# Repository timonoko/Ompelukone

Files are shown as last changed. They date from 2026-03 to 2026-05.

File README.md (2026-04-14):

Merkittävää kenties se, että käytin zero-detecting optotriaccia, vaikka tekoäly suositteli analogista ratkaisua.
Uusi 11 millisekunnin kytkentätaajuus tuottaa satunnaisesti 10 ms half-cycle pulsseja ja meno on tasasta kuin modellinukella kaubamajan akkunassa.

Ei mikä tahansa rampparulla. Singer Slant-o-matic 1957 maksaa satasia Ebayssa.

Jos käynnistää kaasu pohjassa, se kytkeytyy nettiin ja siitä tulee webrepl-serveri.

Ompelukokemus on paljastanut, että vehje on niin hyvissä rasvoissa, että käyntiinlähtötilanne on hieman epämääräinen ja tahmea. Siksi siinä on nyt 40ms pulssi, joka nykäiseen moottorin liikkeelle.

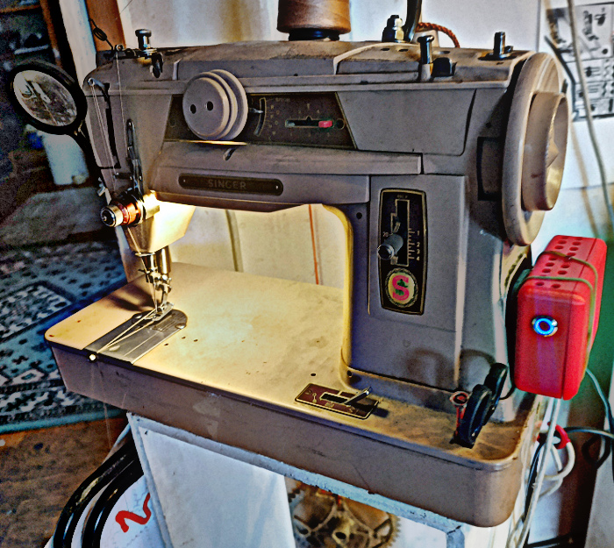
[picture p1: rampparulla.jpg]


Nyt siinä vauhtianturi, joka on Walkman kasettimankan moottori.

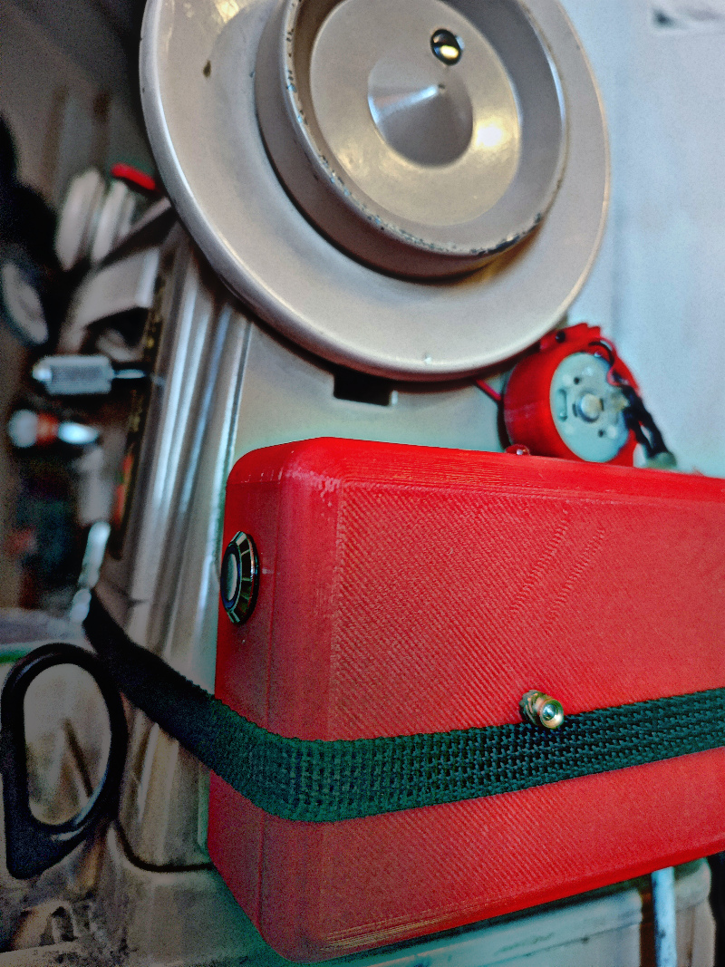
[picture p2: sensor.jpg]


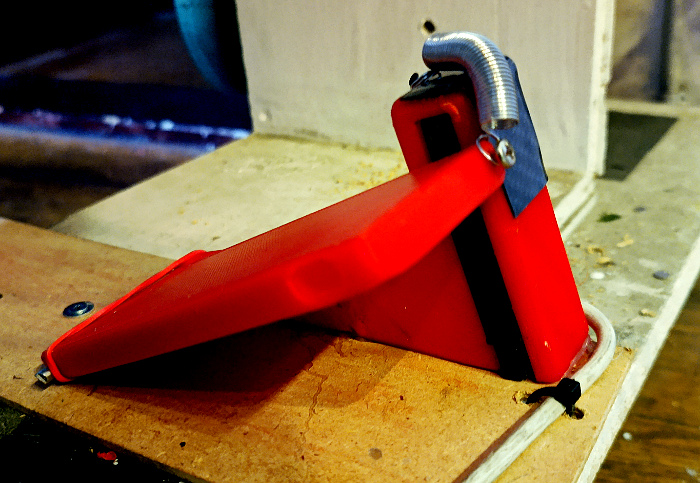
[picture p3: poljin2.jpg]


https://youtube.com/shorts/d1vxEruO6-g?si=aJA7WQgHlC6sGKzD

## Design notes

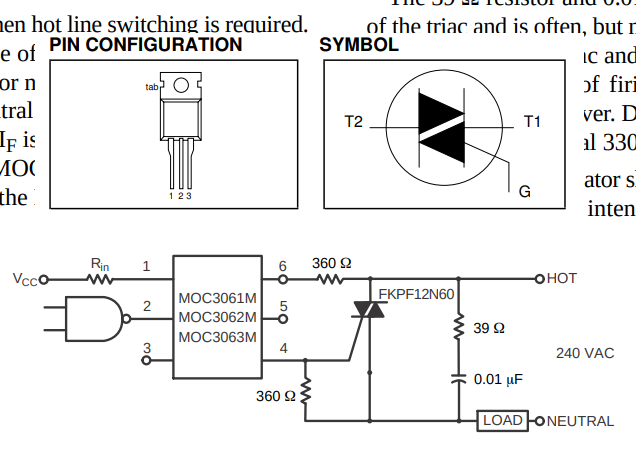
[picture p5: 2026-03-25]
triac.png

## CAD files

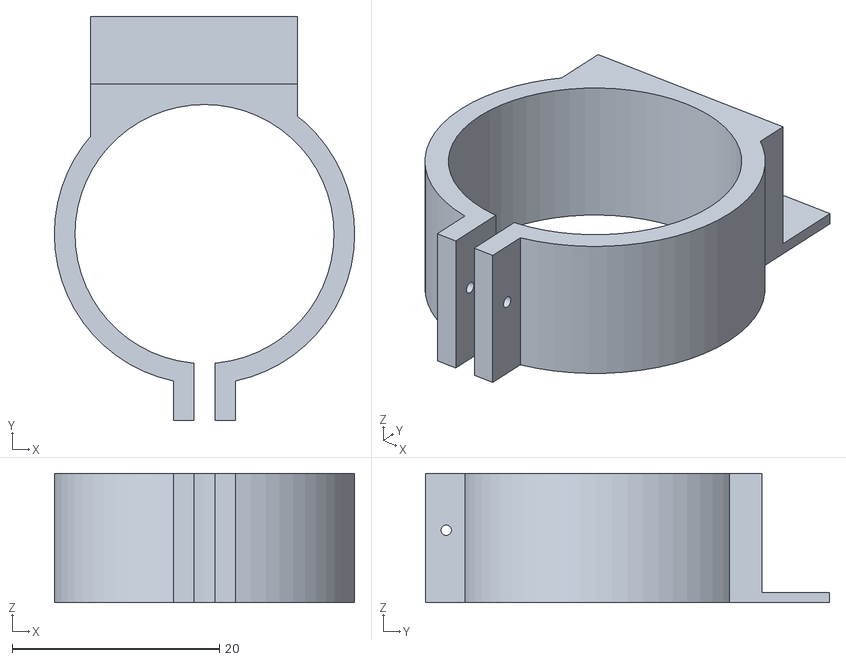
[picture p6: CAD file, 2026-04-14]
anturi.stl
29.0 x 39.0 x 12.5

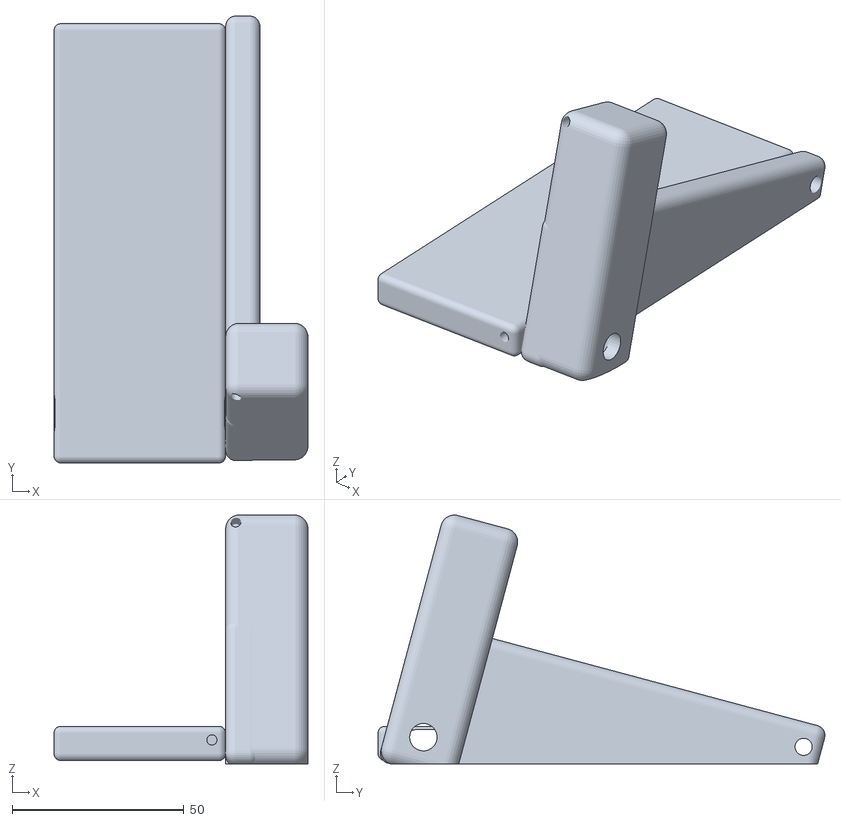
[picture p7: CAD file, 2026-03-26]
poljin.stl
74.0 x 130.2 x 72.5

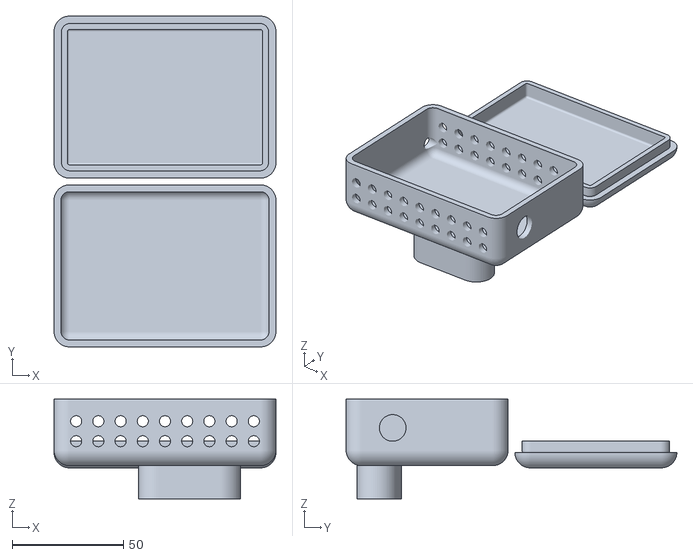
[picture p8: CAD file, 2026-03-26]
ompelukoneen_topseli.stl
100.0 x 149.0 x 45.0

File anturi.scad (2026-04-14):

$fn=60;
difference() {
  union()  {
    cylinder(d=25+4,h=12.5);
    translate([-11,0,0])cube([20,29/2,12.5]);
    translate([-3,-18,0])cube([6,5,12.5]);
  }
  cylinder(d=25,h=12.5+4);
  translate([-1,-19,0])cube([2,7,13.5]);
  translate([-5,-16,7])rotate([0,90,0])cylinder(d=1,h=10);
}
translate([-11,13,0])cube([20,8,1]);

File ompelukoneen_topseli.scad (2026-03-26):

include <roundedcube.scad>
$fn=60;

module topseli() {
  difference(){
    hull() {
      cylinder(d=18,h=15);
      translate([(46-18)/2,1,0])cylinder(d=20,h=15);
      translate([46-18,0,0])cylinder(d=18,h=15);
    }
    translate([10/10,1,0]) cylinder(d=5.5,h=18);
    translate([46-18-0.8,1,0])cylinder(d=5.5,h=18);
    translate([(46-18)/2,2,0])cylinder(d=5.5,h=18);
  }
}




width=100;
length=73;
height=36;
radius=7;
thick=3;
lid_height=6;
lip_height=5;

module box () {
difference(){
  roundedcube([width,length,height],radius=radius);
  translate([thick,thick,thick])
  roundedcube([width-2*thick,length-2*thick,height-2*thick],radius=radius-thick);
  translate([0,0,height-lid_height]) cube([width,length,lid_height+1]);
  translate([90,21,17])rotate([0,90,0])cylinder(d=12,h=10);
  translate([0,67,10])rotate([0,90,0])cylinder(d=6,h=10);
 }
}
module lid() {
  difference(){ union(){
      difference(){
	roundedcube([width,length,lid_height+radius],radius=radius);
	translate([0,0,lid_height]) cube([width,length,lid_height+5]);
      }
      difference(){
	translate([thick+0.3,thick+0.3,thick])
	  roundedcube([width-(2*thick)-0.6,length-2*thick-0.6,lid_height+lip_height+radius],radius=radius-thick);
	translate([0,0,lid_height+lip_height]) cube([width,length,lid_height+radius+3]);
      }
    }
    translate([2*thick,2*thick,thick])
      roundedcube([width-4*thick,length-4*thick,lid_height+lip_height+radius],radius=radius-2*thick);
  }
}


module reikia() {
  for (i=[10:10:width-10]){
    translate([i,0,11]) rotate([-90,0,0]) cylinder(d=5,h=length+10);
  }
  for (i=[10:10:width-10]){
    translate([i,0,20]) rotate([-90,0,0]) cylinder(d=5,h=length+10);
  }
}

translate([0,length+3,0])lid();
difference(){  box();reikia(); }


translate([47,14,-15])topseli();

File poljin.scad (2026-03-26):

include <roundedcube.scad>

module poljin() {
  difference(){
    translate([0,-8,0])roundedcube(([50,128,10]),radius=2);
    translate([-7,0,9]) rotate([0,90,0]) roundedcube([7,13,70],radius=3);
    translate([-5,116,4]) rotate([0,90,0]) cylinder(d=5,h=60);
    translate([46,-1,6])rotate([90,0,0])cylinder(d=3,h=10);
  }
}

module teline() {
  difference(){
    translate([0,-8,0])rotate([-15,0,0])
      difference(){
      union(){
	roundedcube([24,23,75],radius=4);
	roundedcube([10,124,43],radius=3);
      }
      translate([-1,6,0])cube([21,10,70]);
      translate([16,11,10])rotate([0,90,0])cylinder(d=8,h=10);
      translate([3,8,72])rotate([90,0,0])cylinder(d=3,h=10);
    }
    translate([-50,-9,-151]) cube(150);
    translate([-5,116,4]) rotate([0,90,0]) cylinder(d=5,h=20);
  }
}

translate([-50,0,0])
poljin();
teline();

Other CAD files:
roundedcube.scad

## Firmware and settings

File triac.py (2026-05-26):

import network,time,machine,socket
from machine import Pin,Timer,ADC

triac=Pin(5, Pin.OUT)  
triac.value(0)

pot = ADC(Pin(15))
pot.atten(ADC.ATTN_11DB)       #Full range: 3.3v

sensor = ADC(Pin(4))
sensor.atten(ADC.ATTN_11DB)       #Full range: 3.3v

blue_led = Pin(2, Pin.OUT)  
blue_led.value(0)

goal_speed = 1  # -10 to 10
step_counter = 0

def apply_power(t):
    global step_counter
    if step_counter == 0:
        step_counter = goal_speed
        if step_counter < 0: triac.value(1)
        else: triac.value(0)
    elif step_counter < 0:
        triac.value(0)
        step_counter+=1
    else:
        triac.value(1)
        step_counter-=1

tim = Timer(1)

def set_speed(value):
    global goal_speed,tim
    tim.init(period=11, mode=Timer.PERIODIC, callback=apply_power)
#    goal_speed = round(value/5.-10)
    goal_speed = round(value/2.-25)
    if goal_speed==0: goal_speed=1
    print(f"Motorspeed: {int(value)}")

if pot.read()>2000: # if throttle is at max: network connection
    import network_config
    while True:
        print('network')
        time.sleep(1)
        
zero_point=50

while pot.read()>zero_point:
    blue_led.value(1)
    time.sleep(0.1)
    blue_led.value(0)
    time.sleep(0.1)

blue_led.value(0)

#speed sensor from old walkman motor
WALKMAN=0   
PREV_WALKMAN=0
count=Timer(2)
def count_speed(t):
    global WALKMAN
    WALKMAN=0.9 * (WALKMAN + 0.1*sensor.read())
def start_count():
    global PREV_WALKMAN
    PREV_WALKMAN=10 # avoid 0==0 trap
    count.deinit()
    count.init(period=10, mode=Timer.PERIODIC, callback=count_speed)

previous_speed=0
stopped=True
while True:
  time.sleep(0.01)
  pot_pedal = pot.read()
  pedal=(pot_pedal-zero_point)
  if pot_pedal<zero_point:
      if not stopped:
          stopped=True
          triac.value(0)
          tim.deinit() # This kills the background timer completely
          count.deinit()
          WALKMAN=0
  else:
      if stopped:
          triac.value(1)
          time.sleep(2*1./50) # initial boost for the motor
          triac.value(0)
          stopped=False
          start_count()
      elif PREV_WALKMAN==WALKMAN: start_count()
      else: PREV_WALKMAN=WALKMAN
      diff=(pedal-WALKMAN)/20 # 5 was too jerky
      lazyness=0.1
      previous_speed= lazyness*previous_speed + (1.0-lazyness)*diff
      set_speed(previous_speed)
      time.sleep(0.2)

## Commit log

2026-03-26 uusi poljin
    [poljin.scad, poljin.stl]
2026-03-27 Update README with new switching frequency details
    Added information about the new switching frequency and its effects.
2026-03-29 Update README with webrepl-server feature
    Added information about starting the device with gas pedal down to enable webrepl-server.
2026-04-14 speed sensor
2026-04-14 Add speed sensor information to README
2026-04-14 Fix typo in README regarding Walkman motor
